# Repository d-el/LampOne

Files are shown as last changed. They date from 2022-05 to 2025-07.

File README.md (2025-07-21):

# LampOne

Lamp appearance. For more photos to /Photo.
Lamp without diffuser
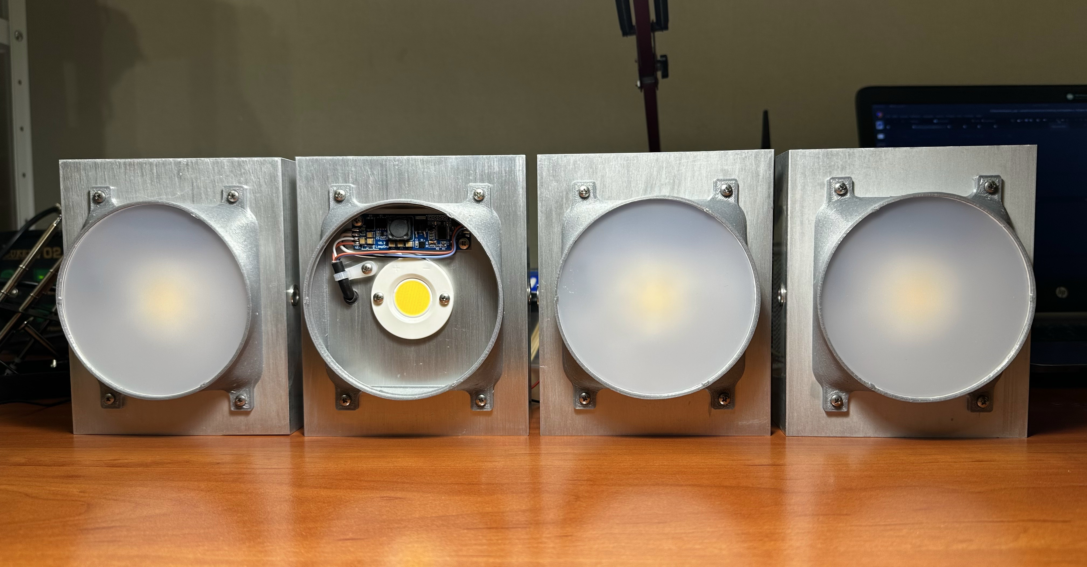
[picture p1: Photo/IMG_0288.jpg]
First 4 assembly

Connector

## Overview  
  - Dimension (without bracket) 128x150x58 mm  
  - weight (without bracket) 695 g

## LED  
LED Cree CXB2530-0000-000N0HU440G, characteristics at IF = 800 mA, TJ = 85 °C:  
  - CCT 4000K  
  - CRI min 80  
  - Flux 3955

## LED Driver  
  - input voltage: 6 - 26 V, recommended 24 V  
  - output current 0.01 - 1.5 A
  - power: up to 60 W  
  - save settings to flash  
  - RS485 ModBus for calibration and control  
  - output power is limited when temperature is greater than 85 °C  
  - output power is linear limited if the input voltage is less than 15.0 V, At 6.0 V maximum output current is 0.3 A  
  - smooth button control from 10 mA to 1 A  
  - temperature compensation
 
 Driver schematic:
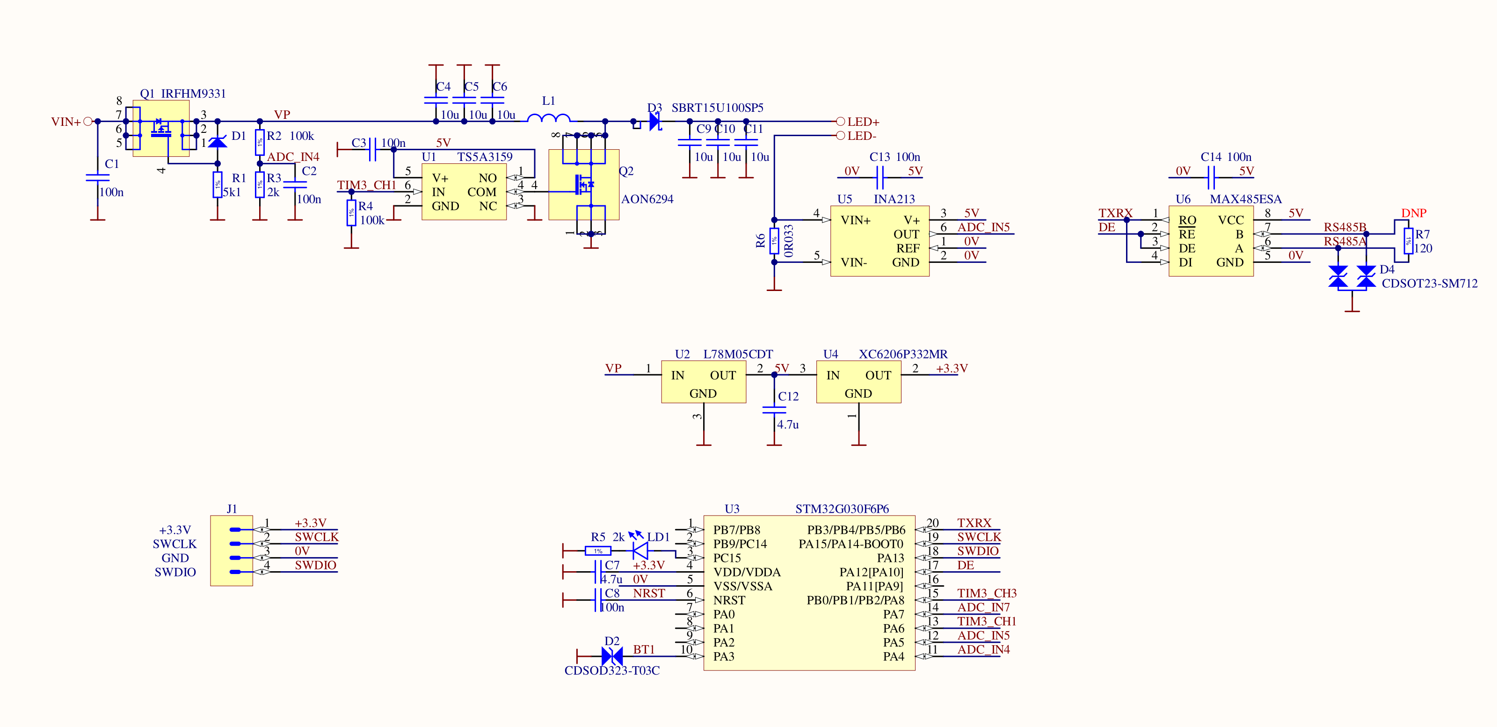
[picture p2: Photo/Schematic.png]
Schematic
 

## Connection  
  - use 5 pin connector, pinout:
    - 1 (white)  - GND
    - 2 (red)    - Power +6-26V
    - 3 (brown)  - RS485 B
    - 4 (violet) - RS485 A
    - 5 (black)  - Switch button

## Temperature compensation
It works according to the formula: $setpoint = setcurrent * (termalThreshpoint - temperature)^2$  
The work of compensation on a real hardware is shown below:
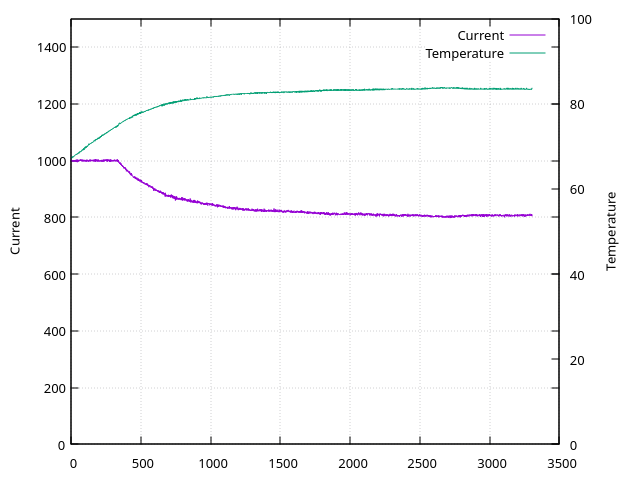
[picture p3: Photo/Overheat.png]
Lamp without diffuser


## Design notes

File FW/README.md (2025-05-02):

# LampOne

## Overview
Firmware of led matrix driver:  
   * constant current mode  
   * MCU: STM32G030F  
   * RS485 ModBus  
   * smooth button control  
   * Temperature compensation  

## Requirements
toolchain arm-none-eabi 10.3 or higher  
gcc / g++ 7.5.0 or higher  
cmake 3.14 or higher  
libjsoncpp-dev  

## Build project
>mkdir build  
>cd build  
>cmake .. -G "Unix Makefiles" -DCMAKE_TOOLCHAIN_FILE=../toolchain.cmake  
>make -j8  

### Start debug server
>./scripts/gdb-serv.sh openocd-jlink

### Start debug client
>./scripts/gdb-client.sh

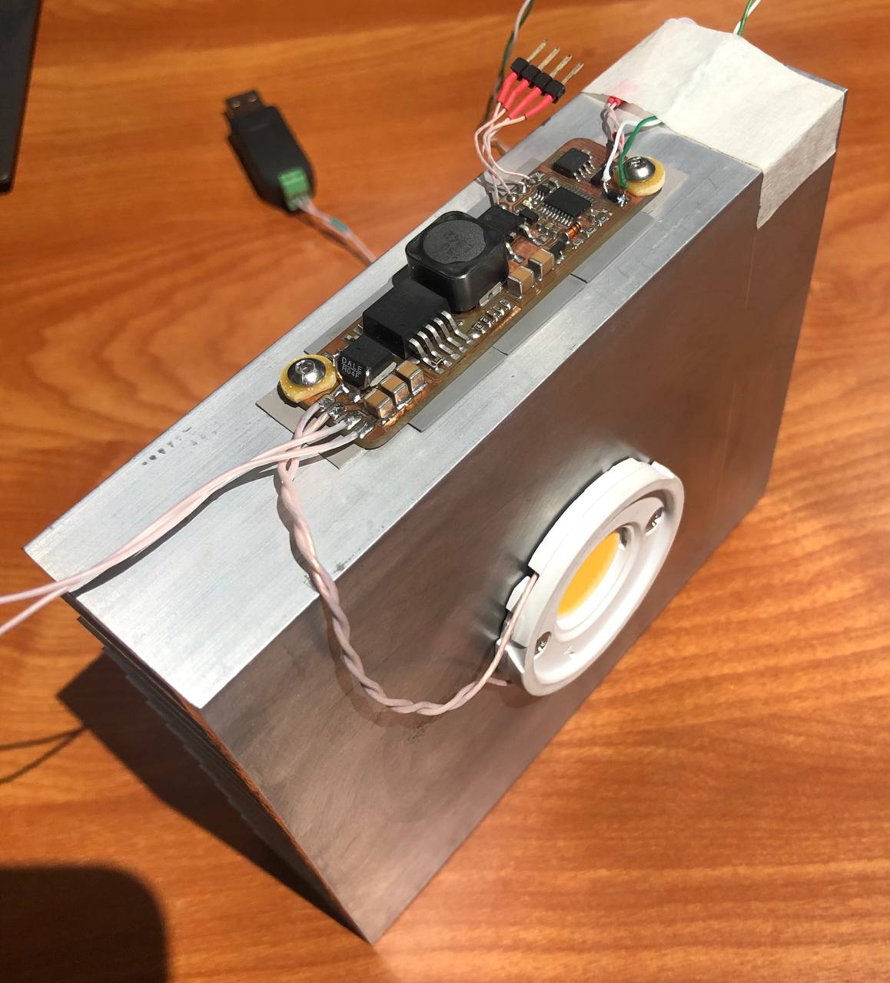
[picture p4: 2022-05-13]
Photo/prototype.jpg

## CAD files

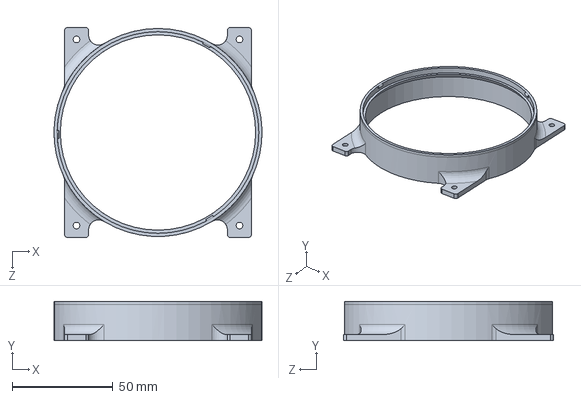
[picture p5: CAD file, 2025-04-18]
Model/Diffuse holder.SLDPRT
103.4 x 19.4 x 104.5 mm

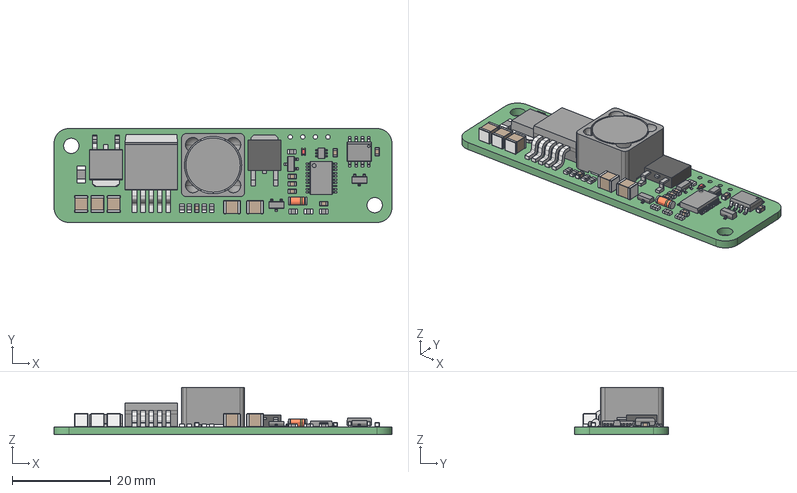
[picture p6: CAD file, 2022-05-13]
PCB/LampOne.step
68.4 x 19.0 x 9.59 mm
RESC1608X55N x 8
User_Library-LED_0603_R_Pocket002
User_Library-LED_0603_R_Pad004
User_Library-LED_0603_R_Fillet
User_Library-LED_0603_R_Pocket001
User_Library-LED_0603_R_Pad
SOT95P240X110-3N
DIOMELF3515N
CAPC1608X87N x 7
CAPC3225X270N x 5
TO170P1524X483-6N-R886X1067
SOT95P280X115-3N
SOT65P210X110-6N
Extruded x 14
SOIC127P600X175-8N
SOP65P640X110-20N
RESC3216X80N
IND_BOURNS_PM127SH
SOT95P240X130-3N
TO228P991X239-3N-R552X520

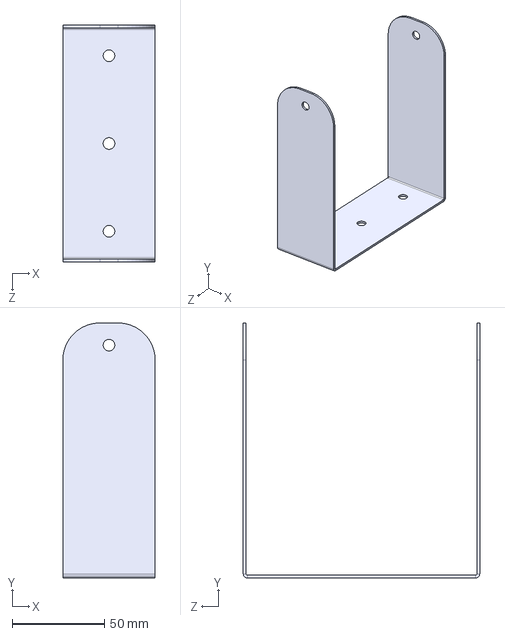
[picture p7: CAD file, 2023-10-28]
Model/bracket.STEP
50.0 x 138.0 x 128.0 mm

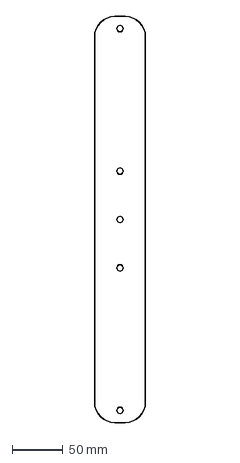
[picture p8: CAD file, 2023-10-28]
Model/Flat-pattern-bracket.DXF
50.0 x 399.0 mm

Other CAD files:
Model/Diffuse holder.STL
Model/bracket.SLDPRT

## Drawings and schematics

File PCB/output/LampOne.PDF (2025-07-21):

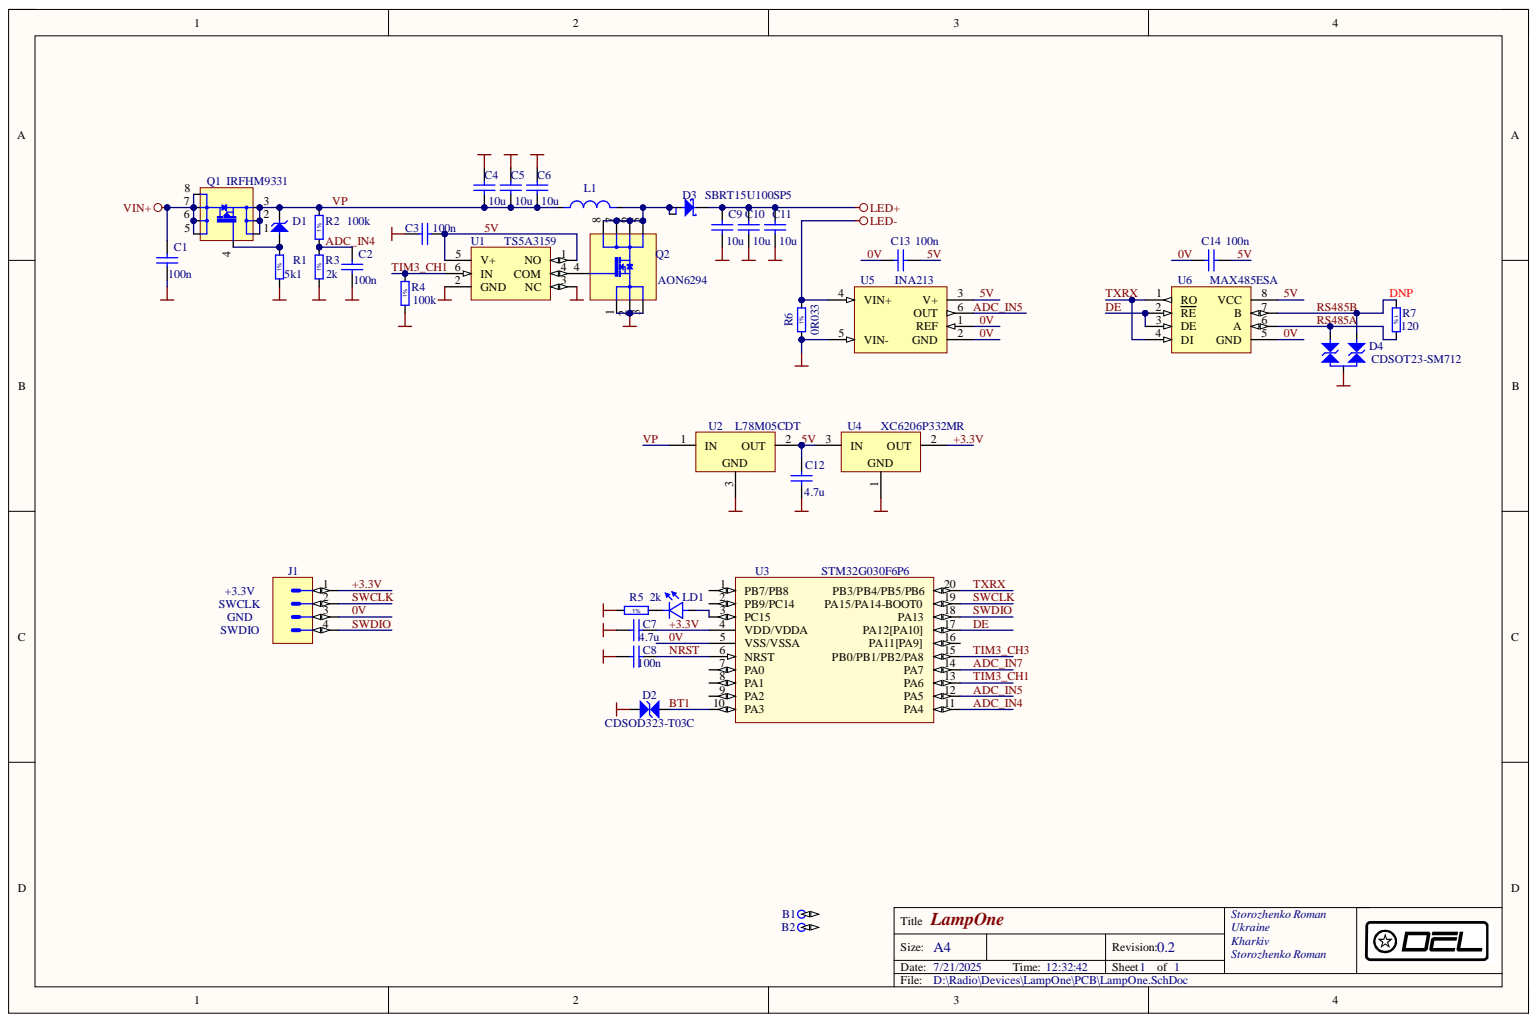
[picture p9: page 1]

Designator | Comment | Footprint | Part Number | Part Description | Quantity
B1, B2 | Non Plated Hole | MTG600H320V8P | NON-PLATED_HOLE3.2_PAD6.0_8p | Through Hole: Hole Dia.=3.2mm Pad Dia.=6mm + 6 Via Dia.=0.3mm | 2
C1, C2, C3, C8, C13, C14 | 100n | CAPC1608X87N | CC0603_100NF_50V_10%_X7R | SMD Multilayer Chip Ceramic Capacitor | 6
C4, C5, C6, C9, C10, C11 | 10u | CAPC3225X270N | CC1210_10UF_50V_10%_X7R | SMD Multilayer Chip Ceramic Capacitor | 6
C7, C12 | 4.7u | CAPC1608X87N | CC0603_4.7UF_10V_10%_X5R | SMD Multilayer Chip Ceramic Capacitor | 2
D1 | BZV55-B10 | DIOMELF3515N | BZV55-B10 | Voltage Regulator Diode | 1
D2 | CDSOD323-T03C | SOD2512X110N | CDSOD323-T03C | TVS Diode | 1
D3 | SBRT15U100SP5 | SBRT15U100SP5 | SBRT15U100SP5 | Schottky Rectifier | 1
D4 | CDSOT23-SM712 | SOT95P240X130-3N | CDSOT23-SM712 | TVS Diode | 1
J1 | Header 4 | 3M_2304-6111-TG | 3M_2304-6111-TG | 4 Contacts - Vertival Contacts Straight Strip Header Pitch 2.54 | 1
L1 | 10uH | IND_BOURNS_PM127SH | IND_10UH_20%_SUMIDA_CDRH125 | Shielded SMD Power Inductors CDRH125 Series | 1
LD1 | Red | LEDC1608X80N_RED | LED_ROHM_SML-311UTT86K | Low current chip LED SML-311 Serie | 1
Q1 | IRFHM9331 | PQFN50P300X300X100_HS-9N | IRFHM9331TRPbF | -30V 11A 0.014 Ohm P-Channel MOSFET | 1
Q2 | AON6294 | DFN-5X6-8L | AON6294 | 100V N-Channel AlphaMOS | 1
R1 | 5k1 | RESC1608X55N | R0603_5K1_1%_0.1W_100PPM | General Purpose Thick Film Chip Resistor | 1
R2, R4 | 100k | RESC1608X55N | R0603_100K_1%_0.1W_100PPM | General Purpose Thick Film Chip Resistor | 2
R3, R5 | 2k | RESC1608X55N | R0603_2K_1%_0.1W_100PPM | General Purpose Thick Film Chip Resistor | 2
R6 | 0R033 | RESC3216X80N | R1206_0R033_1%_0.25W_100PPM | Low Value Flat Chip Resistor | 1
R7 | 120 | RESC1005X40N | R0402_120R_1%_0.0625W_100PP M | General Purpose Thick Film Chip Resistor | 1
U1 | TS5A3159 | SOT65P210X110-6N | TS5A3159DCKR | 1-Ω SPDT Analog Switch | 1
U2 | L78M05CDT | TO228P1010X239-3N-R521X544 | L78M05CDT-TR | 3-Terminal 5V 0.5A Positive Voltage Regulator | 1
U3 | STM32G030F6P6 | SOP65P640X110-20N | STM32G030F6P6 | Arm® Cortex®-M0+ 32-bit MCU | 1
U4 | XC6206P332MR | SOT95P280X115-3N | XC6206P332MR | 3-Terminal 3.3V 200mA Positive Voltage Regulator | 1
U5 | INA213 | SOT65P210X110-6N | INA213xID | Current-Shunt Monitors, –0.3 V to 26 V | 1
U6 | MAX485ESA | SOIC127P600X175-8N | MAX485ESA | Low-Power, Slew-Rate-Limited RS-485/RS-422 Transceivers | 1

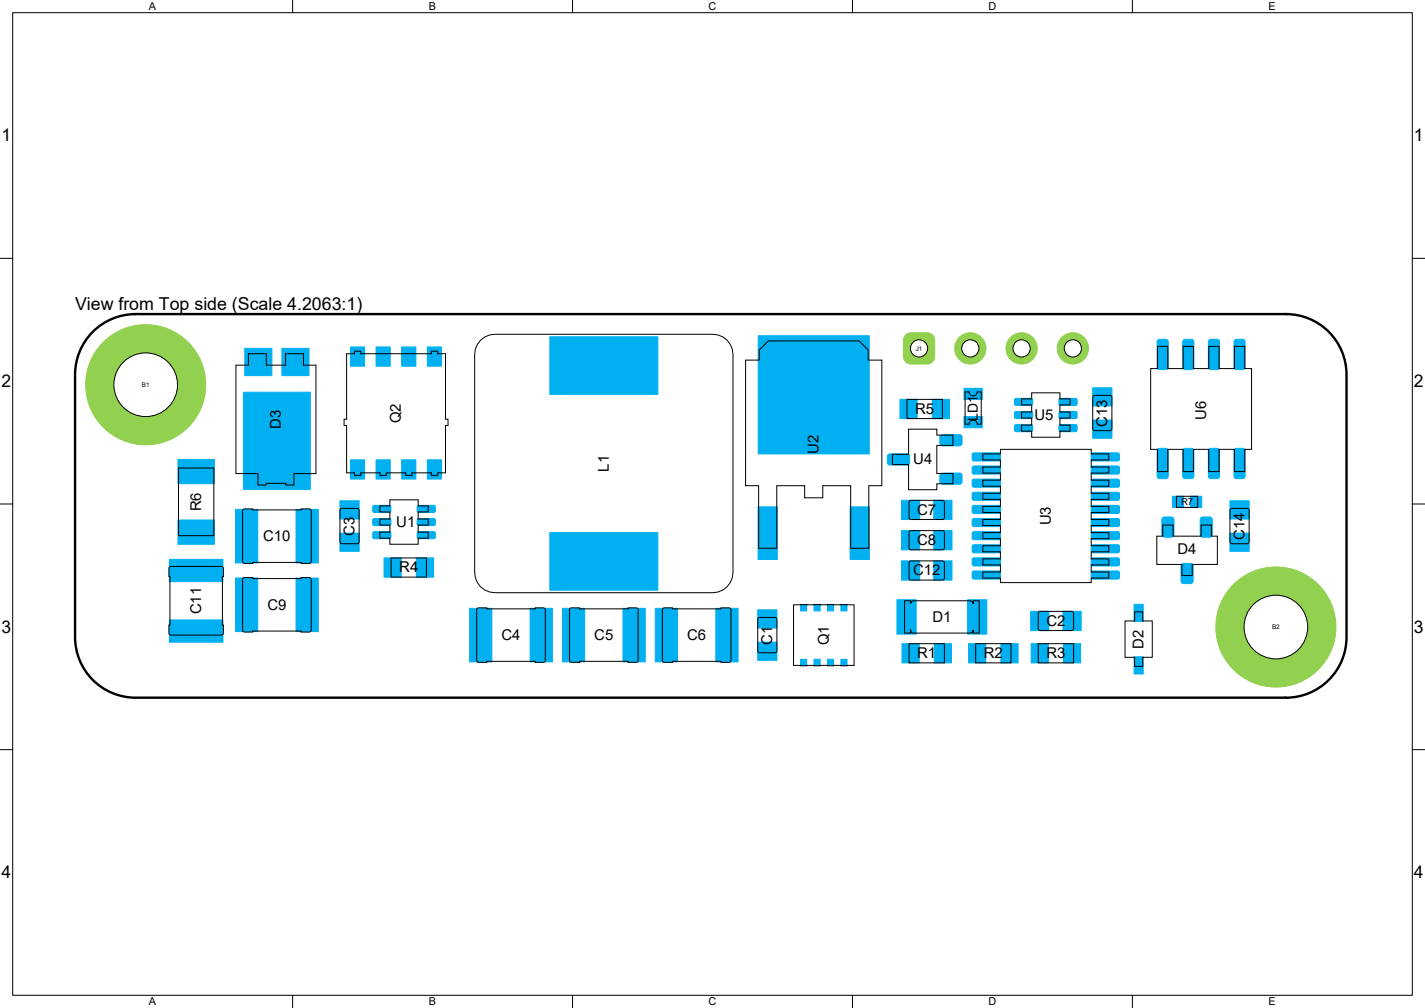
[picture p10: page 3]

View from Top side (Scale 4.2063:1)

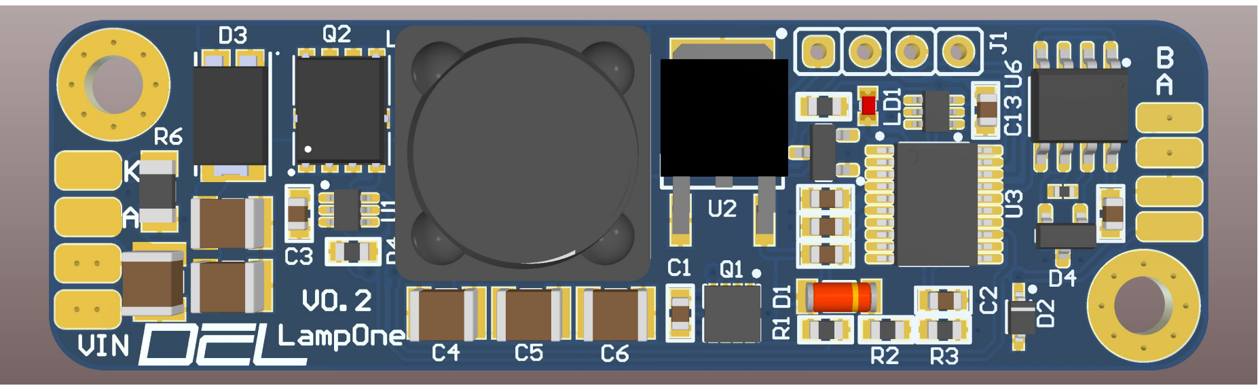
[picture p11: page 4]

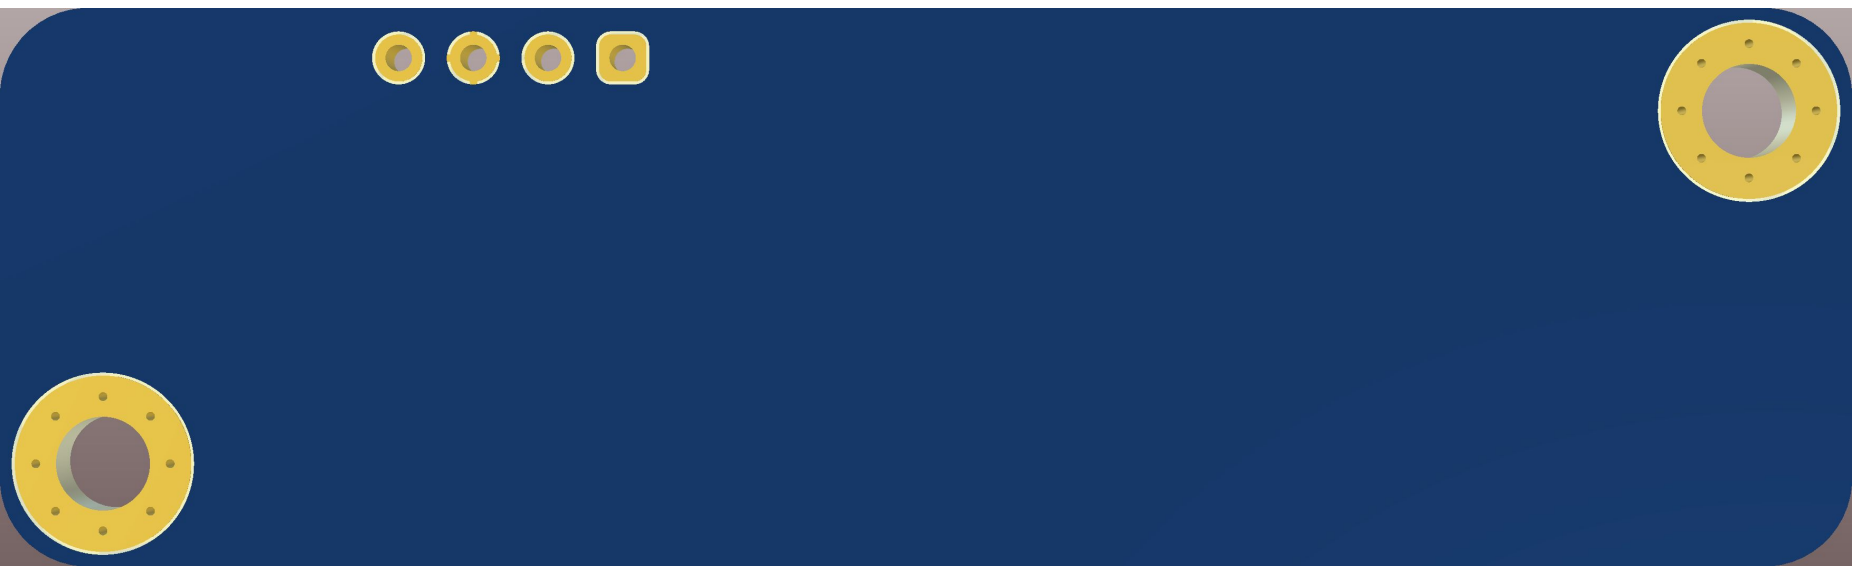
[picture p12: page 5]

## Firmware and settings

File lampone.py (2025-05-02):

#!/usr/bin/env python3
# read and write parameters and calibration
# ./lampone.py /dev/ttyUSB0 --setc=1000 --save

import pymodbus.client as modbusClient
from pymodbus import ModbusException
from collections import OrderedDict
from datetime import datetime
import argparse
import time
import csv
import os
import subprocess
from colorama import Fore, Back, Style

parser = argparse.ArgumentParser(description="LampOne calibration util")
parser.add_argument("serial", help="Serial port name")
parser.add_argument("-a", "--address", type=int, default=1, help="Slave device address, 0 is broadcast")
parser.add_argument("--setaddress", type=int, help="Set device slave address from broadcast")
parser.add_argument("--setc", type=int, help="Set current")
parser.add_argument("--save", help="Save current", action="store_true")
parser.add_argument("--ulvo_voltage", type=int, help="Set ulvo voltage")
parser.add_argument("--ulvo_hysteresis", type=int, help="Set ulvo hysteresis")
parser.add_argument("--voltage_threshold", type=int, help="Set voltage_threshold")
parser.add_argument("--limit_max_current", type=int, help="Set limit_max_current")
parser.add_argument("--limit_min_current", type=int, help="Set limit_min_current")
parser.add_argument("--calc", type=int, help="Calibrate current")
parser.add_argument("-g", "--graph", help="Create graph", action="store_true")
parser.add_argument("-w", help="Wait", action="store_true")
args = parser.parse_args()

print("connection to {}, address {}".format(args.serial, args.address))
client = client = modbusClient.ModbusSerialClient(port=args.serial, baudrate=115200)

def write_register(reg, val, slave_addr):
	result = client.write_register(reg, val, slave=slave_addr)
	if result.isError():
		print(Fore.RED + "Error write reg {:04X} val {}".format(reg, val) + Style.RESET_ALL)

if args.setaddress is not None:
	print("Set slave {}".format(args.setaddress))
	write_register(0x003, args.setaddress, slave=0)
	print("Your need reboot device")
	exit(0)

if args.setc is not None:
	print("Set current {c} mA".format(c=args.setc))
	write_register(0x0100, args.setc, slave=args.address)

if args.save:
	print("Save current")
	write_register(0x0101, 1, slave=args.address)

if args.ulvo_voltage is not None:
	print("Set ulvo_voltage {c} mV".format(c=args.ulvo_voltage))
	write_register(0x0102, args.ulvo_voltage, args.address)
	
if args.ulvo_hysteresis is not None:
	print("Set ulvo_hysteresis {c} mV".format(c=args.ulvo_hysteresis))
	write_register(0x0103, args.ulvo_hysteresis, slave=args.address)

if args.voltage_threshold is not None:
	print("Set voltage_threshold {c} mV".format(c=args.voltage_threshold))
	write_register(0x0104, args.voltage_threshold, slave=args.address)

if args.limit_max_current is not None:
	print("Set limit_max_current {c} mV".format(c=args.limit_max_current))
	write_register(0x0105, args.limit_max_current, slave=args.address)

if args.limit_min_current is not None:
	print("Set limit_min_current {c} mV".format(c=args.limit_min_current))
	write_register(0x0106, args.limit_min_current, slave=args.address)

if args.calc is not None:
	print("Set calibration current {c} mA".format(c=args.calc))
	write_register(0x0300, args.calc, slave=args.address)

v = client.read_holding_registers(0x0000, count=4, slave=args.address)
print("Version {major}.{minor}.{patch}, address {address}".format(major=v.registers[0], minor=v.registers[1], patch=v.registers[2], address=v.registers[3]))

c = client.read_holding_registers(0x0300, count=1, slave=args.address)
print("adcCurrent calibrate {c} mA".format(c=c.registers[0]))
c = client.read_holding_registers(0x0400, count=1, slave=args.address)
print("adcCurrent calibrate {c} lsb".format(c=c.registers[0]))

# Create CSV
filename = ""
if args.graph:
	filename = str(datetime.today().strftime('%Y-%m-%d')) + ".csv"
	f = open(filename, 'w')
	writer = csv.writer(f, delimiter = ",")
	writer.writerow(["Time", "Current", "Temperature"]) # Write heater

while True:
	try:
		r = client.read_holding_registers(0x0100, count=8, slave=args.address)
		print("Target:\n\t" "setcurrent {} mA".format(r.registers[0]))
		print("\tulvo_voltage {} mV".format(r.registers[2]))
		print("\tulvo_hysteresis {} mV".format(r.registers[3]))
		print("\tvoltage_threshold {} mV".format(r.registers[4]))
		print("\tlimit_max_current {} mA".format(r.registers[5]))
		print("\tlimit_min_current {} mA".format(r.registers[6]))
		print("\ttermalThreshpoint {} °C".format(r.registers[7]/10.0))
		
		s = client.read_holding_registers(0x200, count=5, slave=args.address)
		stringstatus = ""
		status = s.registers[4]
		if status == 0:
			stringstatus = " ok"
		if status & 0x01:
			stringstatus = " overheated"
		if status & 0x02:
			stringstatus += " lowInputVoltage"
		if status & 0x04:
			stringstatus += " m_adcOverflow"
		
		current = s.registers[0]
		inputVoltage = s.registers[2]
		temperature = s.registers[3] / 10.0
		
		print("State:\n\t" "current {c} mA\n\tinput_voltage {iv} mV\n\ttemperature {t} °C\n\tstatus:{s}".format(
			c=current, iv=inputVoltage, t=temperature, s=stringstatus))
		
		if args.graph:		
			writer.writerow([current, temperature])
		
		if args.w is not True:
			exit(0)

		time.sleep(0.3)
	
	except KeyboardInterrupt:
		break
	except Exception as error:
		print("An error occurred:", error)

if args.graph:
	proc = subprocess.Popen(['gnuplot','--persist'], 
                shell=False,
                stdin=subprocess.PIPE,
                )

	proc.stdin.write(b"""
		set grid
		set y2tics
		set yrange [0:1500]
		set y2range [0:100]
		set ylabel \'Current\'
		set y2label \'Temperature\'
		set datafile separator ','
		""")
	proc.stdin.write(str.encode("""
		plot \
		\"{file}\" using 1 with lines axis x1y1 title \'Current\',\
		\"{file}\" using 2 with lines axis x1y2 title \'Temperature\'
		""".format(file=filename, title="filename")))
	proc.stdin.write(b"pause -1\n")
	proc.stdin.close()

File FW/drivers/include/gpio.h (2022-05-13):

/*!****************************************************************************
 * @file    	gpio.h
 * @author  	Storozhenko Roman - D_EL
 * @version 	V1.0
 * @date    	22.11.2016
 * @brief    	gpio driver for stm32 G0 microcontroller
 * @copyright 	The MIT License (MIT). Copyright (c) 2020 Storozhenko Roman
 */
#ifndef GPIO_H
#define GPIO_H

#ifdef __cplusplus
extern "C" {
#endif

/*!****************************************************************************
* Include
*/
#include <stdint.h>
#include "stm32g0xx.h"
#include "bitbanding.h"

/*!****************************************************************************
* User define
*/
//MODERy
#define GPIO_INPUT                          0x00
#define GPIO_GP_OUT                         0x01
#define GPIO_AF_MODE                        0x02
#define GPIO_ANALOG_MODE                    0x03
//OTy
#define GPIO_PUSH_PULL                      0x00
#define GPIO_OPEN_DRAIN                     0x01
//PUPDRy
#define GPIO_NO_PULL_UP_DOWN                0x00
#define GPIO_PULL_UP                        0x01
#define GPIO_PULL_DOWN                      0x02
#define GPIO_RESERVED                       0x03
//EXT_I
#define EXTI_MODE_DISABLE                   0x00
#define EXTI_MODE_RISE                      0x01
#define EXTI_MODE_FALL                      0x02
#define EXTI_MODE_BOTH                      0x03

/*!****************************************************************************
* User typedef
*/
typedef enum{
    pinm0   = 1 << 0,
    pinm1   = 1 << 1,
    pinm2   = 1 << 2,
    pinm3   = 1 << 3,
    pinm4   = 1 << 4,
    pinm5   = 1 << 5,
    pinm6   = 1 << 6,
    pinm7   = 1 << 7,
    pinm8   = 1 << 8,
    pinm9   = 1 << 9,
    pinm10  = 1 << 10,
    pinm11  = 1 << 11,
    pinm12  = 1 << 12,
    pinm13  = 1 << 13,
    pinm14  = 1 << 14,
    pinm15  = 1 << 15,
}gpioPin_type;

typedef enum{
    analogMode,                         ///< 0
    digitalInput,                       ///< 1
    outPushPull,                        ///< 2
    outOpenDrain,                       ///< 3
    alternateFunctionPushPull,          ///< 4
    alternateFunctionOpenDrain          ///< 5
}gpioMode_type;

typedef enum{
    speed2MHz,
    speed10MHz,
    speed50MHz,
}gpioSpeed_type;

typedef enum{
    pullDisable,
    pullUp,
    pullDown,
}gpioPull_type;

typedef struct{
    GPIO_TypeDef    *p;                 ///< PORT
    uint16_t        mask;               ///< MASK PIN
    uint8_t         npin;               ///< NUMBER PIN
    gpioMode_type   mode        :3;     ///< MODE
    uint8_t         iniState    :1;     ///< Initial state
    gpioPull_type   pull        :2;     ///< 0 - disable, 1 - pullUp, 2 - pullDown
    uint8_t         nAF         :4;     ///< Number alternate function
}pinMode_type;

typedef enum{
	GP_LED,
	GP_EN1,
	GP_RS485DE,
	GP_BT1_,
	GP_BT1,

GP_NOT_USED
}GPnum_type;

typedef void (*gpioCallback_type)(pinMode_type *gpio);

/*!****************************************************************************
* Macro functions
*/
#define makepin(port, npin, mode, pull, iniState, nAF)    { port, (1<<npin), npin, mode, iniState, pull, nAF }

#define _gppin_set(port, pinmask)       (port->BSRR = (pinmask))
#define _gppin_reset(port, pinmask)     (port->BRR  = (pinmask))
#define _gppin_togle(port, pinmask)     (port->ODR  ^=(pinmask))
#define _gppin_get(port, pinmask)       (port->IDR &  (pinmask))
#define gppin_set(n)                    _gppin_set(pinsMode[n].p, pinsMode[n].mask)
#define gppin_reset(n)                  _gppin_reset(pinsMode[n].p, pinsMode[n].mask)
#define gppin_togle(n)                  _gppin_togle(pinsMode[n].p, pinsMode[n].mask)
#define gppin_get(n)                    _gppin_get(pinsMode[n].p, pinsMode[n].mask)
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

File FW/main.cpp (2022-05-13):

/*!****************************************************************************
* @mainpage                                                                   *
* @file         main.cpp                                                      *
* @author       Storozhenko Roman - D_EL                                      *
* @version      V1.0                                                          *
* @date         10-01-2022                                                    *
* @brief        Main program body                                             *
* @copyright    The MIT License (MIT). Copyright (c) 2022 Storozhenko Roman   *
******************************************************************************/

/*!****************************************************************************
* Include
*/
#include <drivers.h>
#include <systemTSK.h>

/*!****************************************************************************
* @brief    main function
*/
int main(void){
	hardInit();
	OSinit();
	while(1);
	return 0;
}

/******************************** END OF FILE ********************************/

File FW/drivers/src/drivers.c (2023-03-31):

/*!****************************************************************************
 * @file    	drivers.h
 * @author  	Storozhenko Roman - D_EL
 * @version 	V1.0
 * @date    	05.07.2013
 * @copyright 	The MIT License (MIT). Copyright (c) 2020 Storozhenko Roman
 */

/*!****************************************************************************
* Include
*/
#include <string.h>
#include "board.h"
#include "clock.h"
#include "uart.h"
#include "adc.h"
#include "pwm.h"
#include "flash.h"
#include "drivers.h"

/*!****************************************************************************
* MEMORY
*/

/*!****************************************************************************
*
*/
void hardInit(void){
	clock_init();
	gpio_init();
}

/******************************** END OF FILE ********************************/

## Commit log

2023-01-11 update PID and DSP; update schematic to in-loop DSP mode
    [Bill of Materials-LampOne.xls, Bill of Materials-LampOne.xlsx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]
2023-03-31 Add PWM delta-sigma modulator
    [parametres.txt]
2023-10-01 adj regulator
    [LampOne.PrjPcb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]
2023-10-16 Fix modbus init address. Add power limiter by input voltage. Add disabler if input voltage < 'min_input_voltage'
    [LampOne.DXF, parametres.txt]
2023-10-28 Fix component parameter; update model; update script
    [Flat-pattern-bracket.DXF, LampOne.PcbDoc, LampOne.PrjPcb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]
2023-12-01 Add ramp generator Parametrize ULVO Parametrize power limiter vs voltage
    [parametres.txt]
2023-12-08 Fix sample ADC time; Add ADC overflow flag; Clean code; Fix script;
    [parametres.txt]
2024-04-05 Add new parameters
    [LampOne.PrjPcb]
2025-04-18 Add mechanical models
    [Diffuse holder.SLDPRT, Diffuse holder.STL]
2025-05-02 Fix the dependence of the ADC temperature channel on the current; Add oversampling of the temperature channel; Refactor of temperature compensation; Move termalThreshpoint to parmeter;
    [parametres.txt]
2025-05-02 Fix calculate LSB
    [LampOne.SchDoc]
2025-07-21 Minor schenmatic fix; Update README;
    [Bill of Materials-LampOne.xls, Bill of Materials-LampOne.xlsx, LampOne.DXF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]
